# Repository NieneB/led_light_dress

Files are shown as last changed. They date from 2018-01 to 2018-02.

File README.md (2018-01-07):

# Led Light Dress

The things I do to make my dress:

1. [Making a petticoat!](/1_petticoat.md)
2. [Raspberry Pi installation](2_Raspbian_installation)
3. [Setting up Bluetooth connection](/3_Bluetooth.md)
4. [Setting up LED Lights](/4_setting_up_LED.md)
5. [Making dress layers](/5_dress_layers.md)
6. Making dress bodice.

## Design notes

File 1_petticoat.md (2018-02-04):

# Making a Petticoat!

Ordered Tule and Organza. 

6 layers made out of:
	
* Tule Circle skirt 25cm 
* Tule Strip 30 cm x 500 cm
* Decoration ruffle strip(3 diff colours): 750cm x 10cm

First cut all coloured strips and hemmed them with a hemming foot on my sewing machine. So 6 x 7,5 meters! 

Then cut the tule strips. 6 x 5 meter. 25cm wide.
and 6 x circle skirt 25 wide. Diameter of 75cm. Inner circle diameter of 25cm. For my taille circumference is 76cm. `76 / pi = 24.2cm` 
The outer circumference becomes `75 * pi = 235cm`

Then attached the coloured organza strips to the tule strip. Then the tule strip to the circle skirt. 

I cut a 15 cm opening in the circle skirts so I can slip it over my hips. 
Hip circumference is 105 cm. So `105-76 = 29` Needing a cut of `29/2 = 14.5cm`.

The I sewed them all together at the top. 

## Things I learned:

* Using a hemming foot on my sewing machine. I experimented but making a flat hem was too difficult with the thin organza fabric. But using the a zig-zag steek it turned out to be more easy and it gave a beautiful round hem! Still having some silver glitter decoration thread it gave a nice look.
* Calculating fabric need in front. Though I failed this time. Ordered way to much Tule and too less coloured organza. The ruffles would have been nicer if I could have made them longer 10m instead of 7.5m. I could have made them thinner and then longer. so 7.5 cm wide by 10m instead of 10cm by 7.5m. But I was afraid they would become too thin, by hemming them and needing a hem to attach them to the tule strip. Now, I ended up with 7cm wide ruffles after hemming and attaching them.  
* Ordering the right amount of fabric also needs the design to be set and ready. I couldn't make up my mind about the final dress design, plus this also depended on the LED strip possibilities and restrictions. Without having any experience with LED strips I needed to do this project in cycles. Making part of the dress, making part of the LED strips, adjusting the design of the dress to the LED strip restrictions, making the dress, integrating the final LED design.

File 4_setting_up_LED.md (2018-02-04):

# LED strips

## LED strip specifications:
ws2812 DC 
5V ip65 Waterproof 
30 leds/m
power: 9 watt/meter
width:10mm height:2.5mm

FPCB JST-SM connectoren.

Ordered from: https://nl.aliexpress.com/item/DC-5V-12V-WS2811-WS2812B-WS2812-IC-SMD-5050-digital-RGB-Strip-waterproof-Dream-Magic-Full/32823280011.html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

Verbruik: 2Amp per meter when fully lit. 1 when programmed. 0.5 when programmed less bright. 
30 LEDs: 9 Watts (about 1.8 Amps at 5 Volts).

## Hardware
 
Level shifter:

SN74AHCT125N

Specs: https://cdn-shop.adafruit.com/product-files/1787/1787AHC125.pdf

## Software 

What to install:

	sudo apt-get install build-essential python-dev unzip wget scons swig

	wget https://github.com/jgarff/rpi_ws281x/archive/master.zip && unzip master.zip && cd rpi_ws281x-master && sudo scons && cd python && sudo python setup.py install

From https://dordnung.de/raspberrypi-ledstrip/ws2812

## Testing

The variable LED_COUNT is set to the total number of LED chips on the LED-Strip

Then the test is started with:

	sudo python strandtest.py

serieof parralel schAKELEN

serie 
stroom apart 
lus voor data
?? kan dat? 

## Making it portable

2 lead accus. of 6 volt, 4.5AH

**Specs:** 
Part Number: UL4.5-6
Length: 70 ± 2 mm (2.76 inches)
Width: 47 ± 2 mm (1.85 inches)
Container Height: 101 ± 2 mm (3.94inches)
Total Height (with terminal) : 106 ± 2 mm (4.17 inches)
Approx Weight: Approx 0.75kg (1.65lbs)

Diode ? 

If your microcontroller and NeoPixels are powered from two different sources (e.g. separate batteries for each), there must be a ground connection between the two.
https://learn.adafruit.com/adafruit-neopixel-uberguide/best-practices

Lower voltages are always acceptable, 

 I need to power LOTS of NeoPixels and don’t have a power supply that large. Can I use several smaller ones?
Maybe. There are benefits to using a single supply, and large power supplies are discussed below. “Non-optimal” doesn’t necessarily mean “pessimal” though, and we wouldn’t discourage anyone from using what resources they have.

If you go this route, the key is to have all of the ground pins among the strips connected in common, but the +5V from each power supply should be connected only to one length of NeoPixels — those should not all be joined. Every power supply is a little different — not precisely 5 Volts — and this keeps some from back-feeding into others.

Pro Tip: NeoPixels don’t care what end they receive power from. Though data moves in only one direction, electricity can go either way. You can connect power at the head, the tail, in the middle, or ideally distribute it to several points. For best color consistency, aim for 1 meter or less distance from any pixel to a power connection. With larger NeoPixel setups, think of power distribution as branches of a tree rather than one continuous line.

## Limits

control up to 450 LEDs

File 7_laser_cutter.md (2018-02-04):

## Laser cut pieces

Using rasp pi specs I designed the case on the mm exact. Using inkscape. See specs/...pdf.
My design pi_case/case_design_pi3.svg

With M2 screws (just long enough) and some straws, I put the pi floating between 2 pieces of wood.
The prototype board glued on with a glue-gun.

Strips, 12 mm wide and 54 cm long. All with rounded corners, not to break the fabric. The strips give a bit of extra strength to the strips and the soldered connections. Because the leds are not made for wearable uses. Anyways, defining againts all odds, I managed :)

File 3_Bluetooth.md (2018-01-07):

# Setting up Bluetooth connection

	sudo apt-get install bluetooth python-gobject python-gobject-2 blueman bluez python-bluetooth 

	sudo reboot

	sudo bluetoothctl

	[bluetooth]# power on
	[bluetooth]# agent on
	[bluetooth]# discoverable on
	[bluetooth]# pairable on
	[bluetooth]# scan on

	pair <adress phone>

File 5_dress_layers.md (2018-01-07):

## Making dress layers

In total the dress has 4 layers on top of the petticoat. I also added one lining layer underneath the petty coat. 

From bottom to top:

| layer | circle skirt 	| length 	| color | circ waist | diameter | radius |
|---|---|---|---|---| --- |---|
| 1 	| full 			| 55 cm		| pink	| 79cm  	 | 25.15 	| 12.6 |
| 2		| 1.3 			| 50 cm 	| white | 26.33 	 | - 		| 		 | * usd full pattern
| 3		| double 		| 40 cm 	| white | 39.5  	 | 12.6 	| 6.3 |
| 4		| 4 			| 30 cm		| white | 19.75 	 | 6.2 		| 3.15 |
|-------|---------------|-----------|-------|------------|----------|--------|

Hemmed everything with pink thread.

Choices are based on the amount of fabric I had available... Becuase my idea changed a lot and I coudn't make up my mind I just started and ended up with these layers! I did planned a lot, calculated which amount of fabric I would need but it just turned out to be different.

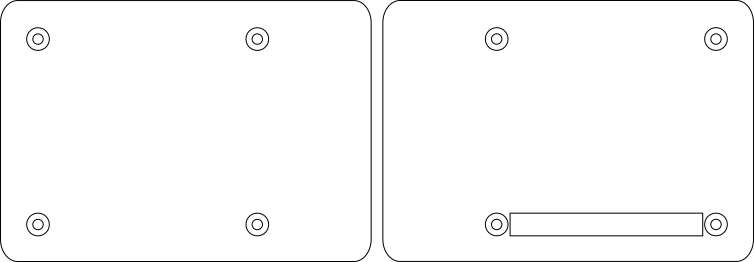
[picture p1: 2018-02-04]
pi_case/rect1290.png

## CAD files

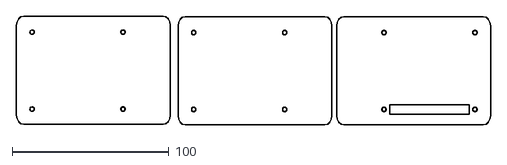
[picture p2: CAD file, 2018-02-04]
pi_case/case_design_pi3.dxf
302.2 x 69.3

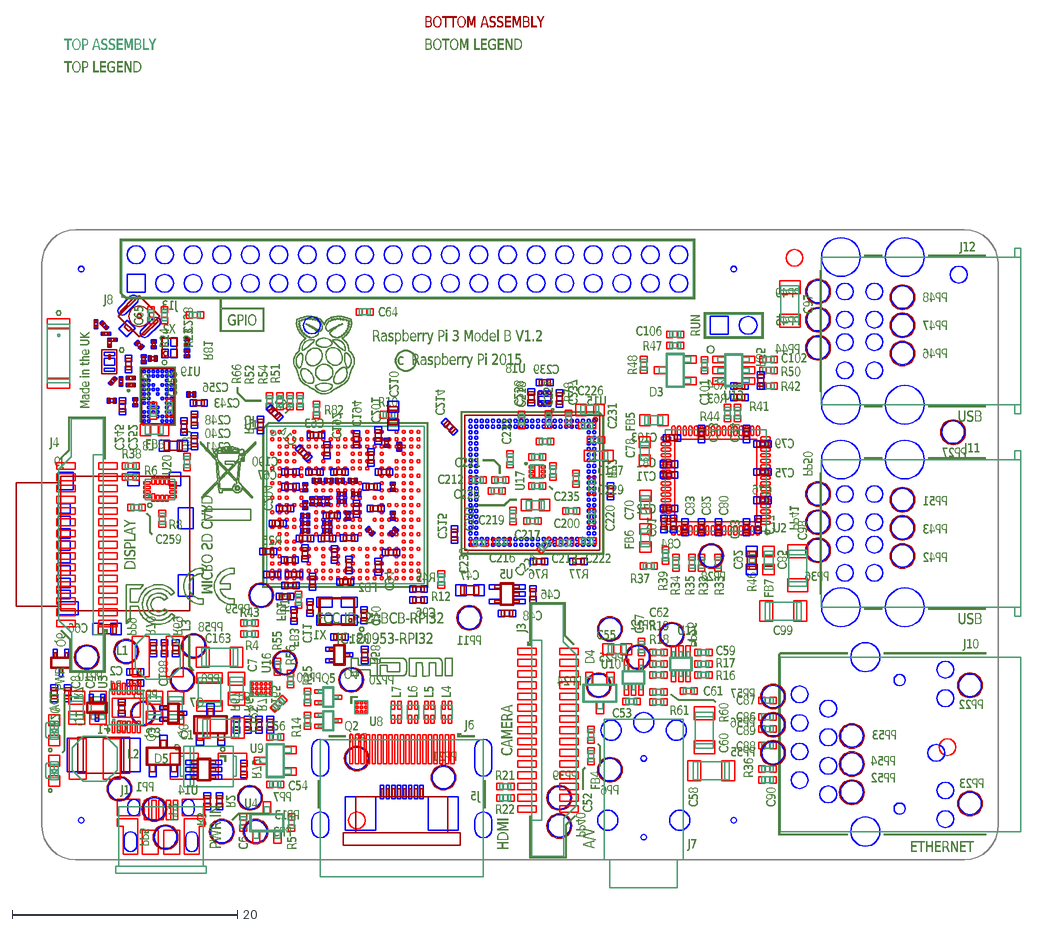
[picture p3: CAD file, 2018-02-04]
pi_case/Raspberry-Pi-3B-V1.2-Mechanical.dxf
J13
U8
U19
U16
X2
F1
J9
U20
U1
L3
R81
C258
C256
C252
U18
U17
U15
U2
J10
R66
R42
R83
R75
R43
R4
R31
R82
R38
R61
R60
R8
R6
R5
R58
R57
R56
R55
R79
R78
R77
R76
R54
R52
R51
R25
R10
R45
R12
R13
R72
R71
R70
R69
R68
R67
R22
R21
R24
R23
R50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

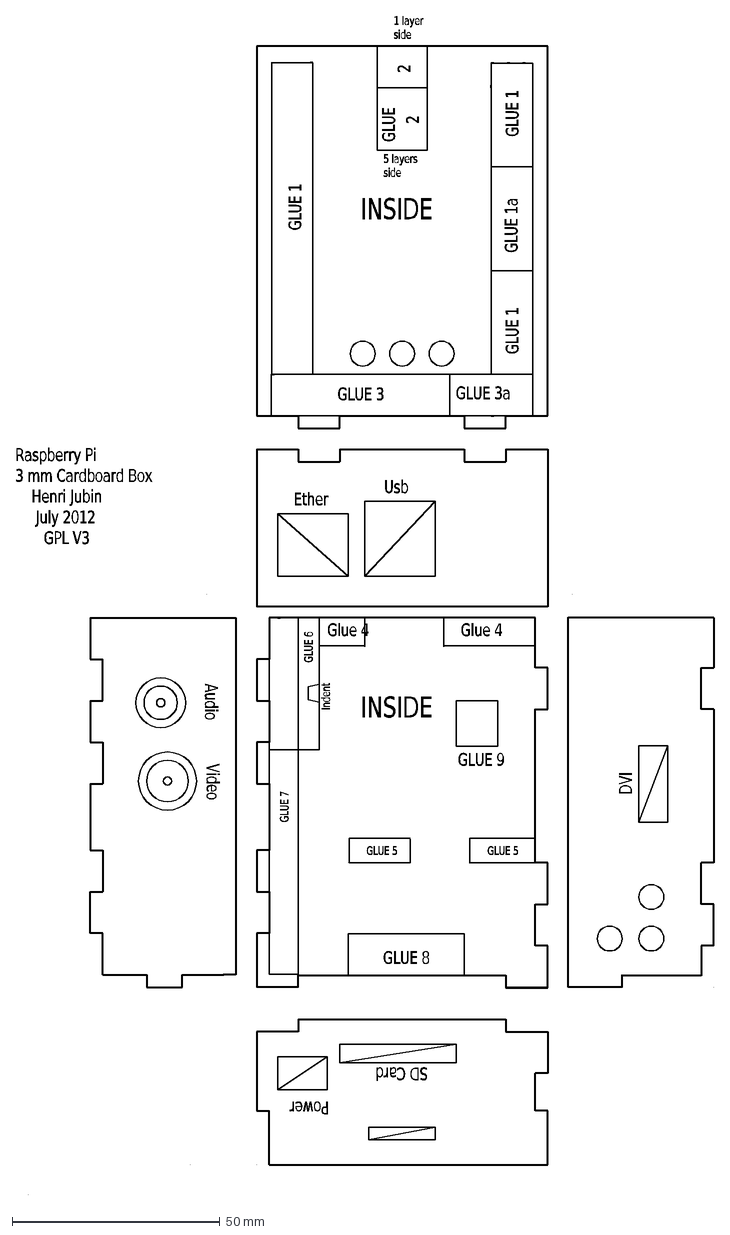
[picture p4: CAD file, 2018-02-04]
pi_case/Raspberry-pi-3mm-foamboard-case.dxf
INSIDE
GLUE
2
GLUE 1
GLUE 5
GLUE 3
1 layer side
5 layers side
GLUE 3a
GLUE 6
Indent
DVI
Video
Audio
Glue 4
Raspberry Pi 3 mm Cardboard Box Henri Jubin July 2012 GPL V3
SD Card
Power
GLUE 1a
Ether
Usb
GLUE 7
GLUE 8
GLUE 9

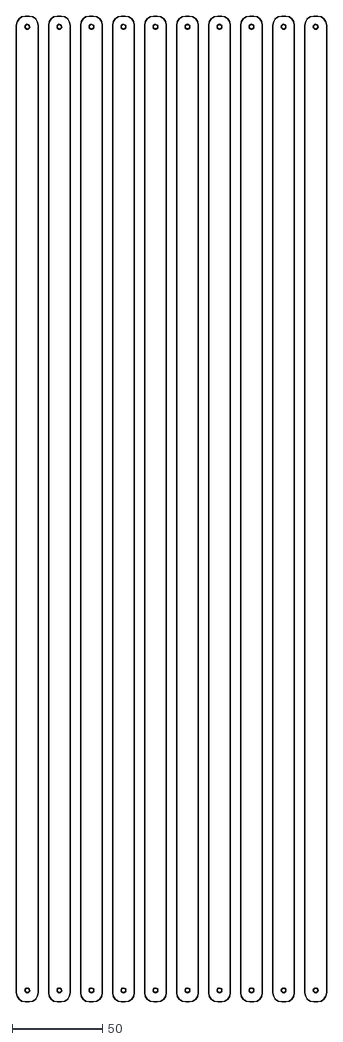
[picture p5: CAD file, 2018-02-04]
pi_case/strips.dxf
171.4 x 545.0

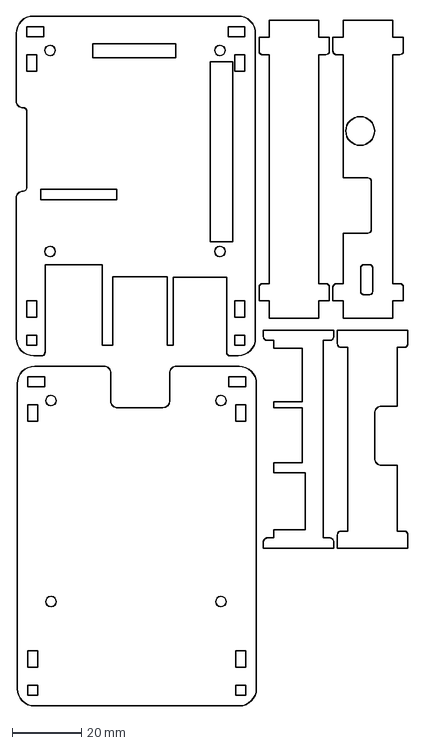
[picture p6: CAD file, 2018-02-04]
pi_case/FU8SXDTIOO5IIEL.dxf
112.9 x 199.0 mm

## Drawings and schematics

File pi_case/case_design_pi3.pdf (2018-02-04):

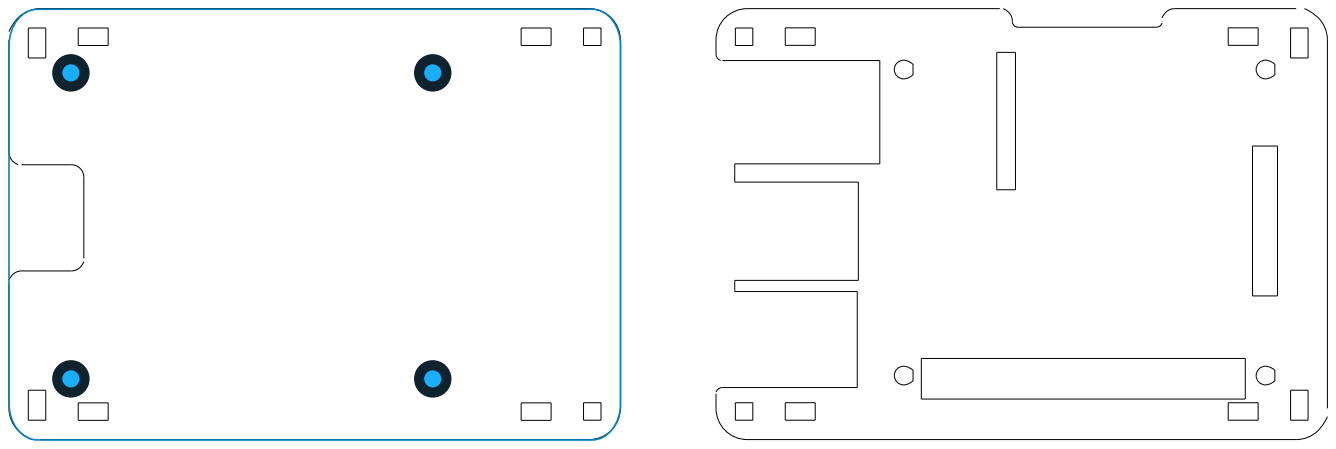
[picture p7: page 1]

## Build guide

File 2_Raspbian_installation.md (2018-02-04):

# Raspberry PI installation

I installed Raspbian Stretch Lite. This because I won't be using any Desktop interface. I connect to the Rapsberry with SSH on my laptop, since I already have experience with this and have no separate screen available.
  
### 1. Format SD card and install Raspbian.
I formatted my SD card and installed the Raspbian image on it. For the formatting I followed the steps from: https://www.pcworld.com/article/3176712/linux/how-to-format-an-sd-card-in-linux.html.

Then downloaded the image from https://www.raspberrypi.org/downloads/raspbian/
Using Etcher I wrote this to the SD card, as described in the installation guide. https://www.raspberrypi.org/documentation/installation/installing-images/README.md

### 2. Connecting through SSH
In order to be able to connect through SSH I needed to enable it first on the SD card. So still having the SD card in my laptop, I added a file named `ssh` without any extension or content on the boot partition of the SD card. Now connecting the PI to my network directly into my router with a ether cable, SSH is enabled.  

From my laptop, through the wifi network, I detected the IP address of my PI.

Getting own ip adres:

	ifconfig

Scanning form available ip adresses:

	nmap -sn <IPadres>

See: https://www.raspberrypi.org/documentation/remote-access/ip-address.md

Then with ssh we can connect to it.

	ssh pi@<IPadress> 

Default login password is `raspberry`.

First things first! Change the Password and update the system!

	password
	sudo apt-get update
	sudo apt-get upgrade

	sudo apt-get install build-essential git vim

Get this repro:

	git clone https://github.com/NieneB/led_light_dress.git

## Reducing power consumption
Add `/usr/bin/tvservice -o` to /etc/rc.local

## Clean shutdown raspberry pi

Clean shutdown: 

	sudo shutdown -h now

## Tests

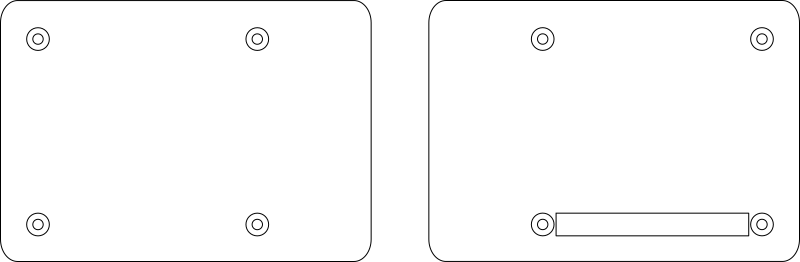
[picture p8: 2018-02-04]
pi_case/test_case.png

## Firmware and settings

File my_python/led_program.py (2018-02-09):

# NeoPixel library strandtest example
# Author: Tony DiCola (tony@tonydicola.com)
#
# Direct port of the Arduino NeoPixel library strandtest example.  Showcases
# various animations on a strip of NeoPixels.
import time

from neopixel import *

import argparse
import signal
import sys
def signal_handler(signal, frame):
        colorWipe(strip, Color(0,0,0))
        sys.exit(0)

def opt_parse():
        parser = argparse.ArgumentParser()
        parser.add_argument('-c', action='store_true', help='clear the display on exit')
        args = parser.parse_args()
        if args.c:
                signal.signal(signal.SIGINT, signal_handler)

# LED strip configuration:
LED_COUNT      = 170      # Number of LED pixels.
LED_PIN        = 18      # GPIO pin connected to the pixels (18 uses PWM!).
#LED_PIN        = 10      # GPIO pin connected to the pixels (10 uses SPI /dev/spidev0.0).
LED_FREQ_HZ    = 800000  # LED signal frequency in hertz (usually 800khz)
LED_DMA        = 10      # DMA channel to use for generating signal (try 10)
LED_BRIGHTNESS = 255     # Set to 0 for darkest and 255 for brightest
LED_INVERT     = False   # True to invert the signal (when using NPN transistor level shift)
LED_CHANNEL    = 0       # set to '1' for GPIOs 13, 19, 41, 45 or 53
LED_STRIP      = ws.WS2811_STRIP_GRB   # Strip type and colour ordering



# Define functions which animate LEDs in various ways.
def colorWipe(strip, color, wait_ms=50):
	"""Wipe color across display a pixel at a time."""
	for i in range(strip.numPixels()):
		strip.setPixelColor(i, color)
		strip.show()
		time.sleep(wait_ms/1000.0)

def theaterChase(strip, color, wait_ms=50, iterations=10):
	"""Movie theater light style chaser animation."""
	for j in range(iterations):
		for q in range(3):
			for i in range(0, strip.numPixels(), 3):
				strip.setPixelColor(i+q, color)
			strip.show()
			time.sleep(wait_ms/1000.0)
			for i in range(0, strip.numPixels(), 3):
				strip.setPixelColor(i+q, 0)

def wheel(pos):
	"""Generate rainbow colors across 0-255 positions."""
	if pos < 85:
		return Color(pos * 3, 255 - pos * 3, 0)
	elif pos < 170:
		pos -= 85
		return Color(255 - pos * 3, 0, pos * 3)
	else:
		pos -= 170
		return Color(0, pos * 3, 255 - pos * 3)

def rainbow(strip, wait_ms=20, iterations=1):
	"""Draw rainbow that fades across all pixels at once."""
	for j in range(256*iterations):
		for i in range(strip.numPixels()):
			strip.setPixelColor(i, wheel((i+j) & 255))
		strip.show()
		time.sleep(wait_ms/1000.0)

def rainbowCycle(strip, wait_ms=20, iterations=5):
	"""Draw rainbow that uniformly distributes itself across all pixels."""
	for j in range(256*iterations):
		for i in range(strip.numPixels()):
			strip.setPixelColor(i, wheel((int(i * 256 / strip.numPixels()) + j) & 255))
		strip.show()
		time.sleep(wait_ms/1000.0)

def theaterChaseRainbow(strip, wait_ms=50):
	"""Rainbow movie theater light style chaser animation."""
	for j in range(256):
		for q in range(3):
			for i in range(0, strip.numPixels(), 3):
				strip.setPixelColor(i+q, wheel((i+j) % 255))
			strip.show()
			time.sleep(wait_ms/1000.0)
			for i in range(0, strip.numPixels(), 3):
				strip.setPixelColor(i+q, 0)

# Main program logic follows:
if __name__ == '__main__':
        # Process arguments
        opt_parse()

	# Create NeoPixel object with appropriate configuration.
	strip = Adafruit_NeoPixel(LED_COUNT, LED_PIN, LED_FREQ_HZ, LED_DMA, LED_INVERT, LED_BRIGHTNESS, LED_CHANNEL, LED_STRIP)
	# Intialize the library (must be called once before other functions).
	strip.begin()

	print ('Press Ctrl-C to quit.')
	while True:
		print ('Color wipe animations.')
		colorWipe(strip, Color(255, 20, 147))  # Pink wipe
		colorWipe(strip, Color(255, 105, 180))  # Light Pink wipe
		colorWipe(strip, Color(255, 182, 193))  # Lighter pink wipe
		print ('Theater chase animations.')
		theaterChase(strip, Color(255, 182, 193))  # White theater chase
		theaterChase(strip, Color(127,   0,   0))  # Red theater chase
		theaterChase(strip, Color(  0,   0, 127))  # Blue theater chase
		print ('Rainbow animations.')
		rainbow(strip)
		rainbowCycle(strip)
		theaterChaseRainbow(strip)

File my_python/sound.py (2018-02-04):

#!/usr/bin/python
import RPi.GPIO as GPIO
import time

#GPIO SETUP
channel = 17
GPIO.setmode(GPIO.BCM)
GPIO.setup(channel, GPIO.IN)

def callback(channel):
 if GPIO.input(channel):
     print GPIO.input(channel)
 else:
      print GPIO.input(channel)

GPIO.add_event_detect(channel, GPIO.BOTH, bouncetime=300)  # let us know when the pin goes HIGH or LOW
GPIO.add_event_callback(channel, callback)  # assign function to GPIO PIN, Run function on change

# infinite loop
while True:
   time.sleep(1)

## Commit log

2018-01-07 set up LED light python library
2018-01-07 set up raspberry
2018-02-04 pi case and strip designs
    [FU8SXDTIOO5IIEL.dxf, Raspberry-Pi-3B-V1.2-Mechanical.dxf, Raspberry-pi-3mm-foamboard-case.dxf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]
2018-02-09 rainbow over all leds
2018-02-10 more buttons
